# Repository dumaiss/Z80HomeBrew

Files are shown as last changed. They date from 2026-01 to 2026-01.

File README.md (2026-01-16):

# Z80 HomeBrew Single-Board Computer

A compact Z80-based single-board homebrew computer designed to run CP/M and provide classic retro I/O and expansion.

## Overview

This board implements a banked-memory Z80 system with modern conveniences (SD storage, USB peripherals) while keeping vintage-compatible subsystems (TMS9928 video, SN76489 sound). It's intended for hobbyists building or experimenting with CP/M and retro software.

## Features

- **CPU**: Z80-compatible core
- **RAM**: 512KB, banked (Z80 address banking for CP/M usage and extended RAM experiments)
- **ROM**: 32KB EEPROM for bootloader/firmware
- **Storage**: SD Card support for disk images and CP/M volumes
- **USB Serial**: USB serial port for terminal access and debug console
- **USB Input**: USB keyboard plus D-Pad support for interactive input
- **Sound**: SN76489-compatible sound chip for PSG audio
- **Video**: TMS9928-based output; YPbPr analog video output supported
- **Expansion**: mini-PCIe style expansion slot for additional cards or peripherals
- **Power**: Designed to run from a regulated 5V wall power supply

## Hardware Notes

- The 512KB RAM is banked to map into the Z80 64KB address space as needed by the firmware or CP/M.
- The 32KB EEPROM contains the primary bootloader/firmware; update via the board's programming interface (refer to device-specific docs).
- Video uses a TMS9928-compatible video pipeline exposed as YPbPr analog output; a compatible monitor or converter is required.
- Sound is provided by an SN76489-compatible PSG; connect to an amplifier or powered speakers for audio output.
- The mini-PCIe expansion slot exposes power, bus, and selected signals for optional modules; treat it as an extension header for retro or modern expansion boards.

## Getting Started

1. Prepare an SD card with a CP/M image or disk set compatible with the board.
2. Insert the SD card into the board's slot.
3. Connect YPbPr video to a compatible display, or use the USB serial console and a USB keyboard.
4. Attach a regulated 5V wall power supply (check current rating in hardware docs before powering).
5. Power on the board — the bootloader in EEPROM should initialize and boot from the SD card if present.

Notes:
- Use a terminal program (e.g., `screen`, `minicom`, or a serial terminal application) to connect to the USB serial console if you prefer working without the video output.
- If flashing firmware to the EEPROM or updating boot code, follow the project's programming instructions or tooling.

## Power

The board is designed to operate from a single regulated 5V DC wall supply. Verify the supply can deliver sufficient current for attached peripherals (SD, USB devices, any expansion cards). Avoid using unregulated or higher-voltage supplies.

## Files

See the project Licence: [Licence.md](Licence.md)

## Contributing

Contributions, improvements, and bug reports are welcome. Open issues or pull requests with hardware notes, firmware updates, or SD images that improve the CP/M experience.

---

If you want, I can add wiring diagrams, pinouts, a sample CP/M SD image guide, or a small troubleshooting section next.

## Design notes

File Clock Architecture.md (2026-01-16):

Here is the complete architectural summary for the μBITz clock system, capturing the "Parallel Clock" design using the 24.576 MHz oscillator.

---

# Homebrew Z80 Clock Distribution Architecture

## 1. Design Overview

This architecture uses a single high-speed master oscillator (**24.576 MHz**) to drive the entire system. The clock signal is split at the source ("Parallel Distribution"):

1. **Path A (Logic):** Feeds a hardware divider (74HC4040) to generate fixed, 50% duty cycle clocks for the Z80 CPU and peripherals.
    
2. **Path B (Bridge):** Feeds the ATmega328P directly, utilizing the AVR's internal prescaler to run at a safe 12.288 MHz while retaining the ability to "Turbo" to 24.576 MHz via software.

## 2. Hardware Schematic & Netlist

### Component 1: Master Oscillator

- **Part:** 24.576 MHz "Can" Oscillator (Socketed).
    
- **VCC:** 5V.
    
- **Output:** Connected to **Two** locations:
    
    1. ATmega328P Pin 9 (XTAL1).
        
    2. 74HC4040 Pin 10 (CLK).

### Component 2: Frequency Divider

- **Part:** 74HC4040 (12-Stage Binary Ripple Counter).
    
- **Input (Pin 10):** 24.576 MHz from Oscillator.
    
- **Outputs:**

|**4040 Pin**|**Output**|**Divisor**|**Frequency**|**Destination**|**Notes**|
|---|---|---|---|---|---|
|**Pin 9**|Q0|$\div 2$|12.288 MHz|_Unused_|(Available on header for testing)|
|**Pin 7**|Q1|$\div 4$|**6.144 MHz**|**Z80, SIO, CTC**|Perfect 50% Duty Cycle. Safe for NMOS.|
|**Pin 6**|Q2|$\div 8$|**3.072 MHz**|**SN76489**|Sound Chip. (Requires pitch correction).|

### Component 3: ATmega328P "Smart Bridge"

- **Input (Pin 9):** 24.576 MHz direct from Oscillator.
    
- **Pin 10 (XTAL2):** **Disconnected** (Floating).
    
- **Operation:** Acts as an SPI bridge and I/O offloader.
    
- **Speed:** Selectable 12.288 MHz (Standard) or 24.576 MHz (Turbo).

---

## 3. Software Configuration

### A. ATmega Fuses

You must set the fuses to treat the clock as an External Clock source and enable the safety divider at boot.

- **Low Fuse Byte:** `0x60` (Check specific calculator for your BOD settings).
    
    - **CKSEL[3:0]:** `0000` (External Clock).
        
    - **CKDIV8:** `0` (Programmed/Enabled). _Critical: This forces the chip to boot at ~3 MHz._

### B. ATmega Initialization Code

In your `setup()` function, you must reconfigure the prescaler to speed up the chip to 12.288 MHz.

C++

```
#include <avr/power.h>

// Define system clock for delay calculations (Safe Mode)
#define F_CPU 12288000UL 

void setup() {
    // 1. Chip boots at 3.072 MHz (24.576 / 8) due to CKDIV8 fuse.
    
    // 2. Disable Interrupts during clock change
    noInterrupts();
    
    // 3. Enable Prescaler Change
    CLKPR = (1 << CLKPCE);
    
    // 4. Set Prescaler to Divide-by-2 (0001)
    //    Target: 24.576 MHz / 2 = 12.288 MHz
    CLKPR = (1 << CLKPS0); 
    
    interrupts();
    
    // ... Rest of initialization
}
```

### C. Z80 Sound Driver (Pitch Correction)

Since the SN76489 is running at 3.072 MHz instead of the NTSC standard 3.579 MHz, audio pitches will be flat. The Z80 software must compensate.

- **Correction Factor:** $3.579545 / 3.072 \approx \mathbf{1.1652}$
    
- **Formula:** `Register_Value = Target_Frequency_Register * 1.165`

---

## 4. System Frequency Map

|**Subsystem**|**Frequency**|**Derivation**|**Notes**|
|---|---|---|---|
|**ATmega Core**|**12.288 MHz**|$24.576 / 2$|Configured via `CLKPR`. Safe & Stable.|
|**Z80 CPU**|**6.144 MHz**|$24.576 / 4$|$\sim$2% overclock from 6 MHz.|
|**Z80 UART**|**6.144 MHz**|$24.576 / 4$|Allows 57,600 baud (Divisor 10).|
|**Sound**|**3.072 MHz**|$24.576 / 8$|Flat pitch, 50% duty cycle.|
|**SD Card SPI**|**6.144 MHz**|$F_{CPU} / 2$|Max SPI speed in Safe Mode.|

## 5. Benefits of this Architecture

1. **Decoupled Stability:** The Z80 clock is generated by hardware logic. If the ATmega crashes or resets, the Z80 clock continues uninterrupted.
    
2. **Safety:** The ATmega runs within its datasheet limits (12 MHz @ 5V).
    
3. **NMOS Compatibility:** The 74HC4040 provides a clean 50% duty cycle square wave, essential for the vintage Sharp LH0080B CPU.
    
4. **Overclock Ready:** If you need more processing power for USB HID, you can change one line of code (`CLKPR=0`) to run the ATmega at 24.576 MHz without touching a soldering iron.

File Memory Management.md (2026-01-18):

# Z80 HomeBrew Single-Board Computer

**Memory & I/O Architecture Reference Manual**

## 1. Architecture Overview

This system is a Z80-based single-board computer designed for flexibility, supporting both classic "ColecoVision-style" fixed memory maps and a modern "All-RAM" banked architecture suitable for CP/M or complex homebrew software.

### Core Specifications

- **CPU:** Z80 @ 3.68MHz (or up to 8MHz depending on parts).    
- **RAM:** 512KB Static RAM (Banked).    
- **ROM:** 512KB Flash/EEPROM (Banked).    
- **Memory Controller:** Hybrid design using a **74HC273 Latch** for state storage and a **GAL22V10** for address decoding and logic injection.

---

## 2. Memory Management

The memory management system is designed with a **safe power-on default**. At power-on, the banking latch initializes to $00, placing the system in **Standard Boot Mode** - a ColecoVision-compatible configuration requiring no initialization. The system boots directly into ROM BIOS and is immediately functional. Advanced features (bank switching, All-RAM mode, CP/M) are accessed by writing to the Banking Latch at I/O Port $00.

## 2.1 Usage Patterns

### Pattern A: Simple/ColecoVision Mode (Default - No Setup Required)

**Power-on state provides:**
- ROM BIOS at $0000-$5FFF
- Work RAM at $6000-$7FFF  
- Cartridge or upper RAM at $8000-$FFFF

**No MMU configuration needed** - system is immediately ready. This mode is 
compatible with ColecoVision software and simple applications that don't 
require bank switching.

---

### Pattern B: CP/M / Advanced Mode (Requires Initialization)

For CP/M or applications requiring full 512KB RAM access:

1. **Power-on**: System starts in Boot Mode (ROM_DIS=0)
2. **ROM BIOS executes** from $0000
3. **Enable Shadow Mode**: `OUT ($00), $08` 
4. **Copy BIOS to RAM**: Use `LDIR` to copy $0000-$5FFF to RAM
5. **Switch to All-RAM**: `OUT ($00), $10`
6. **Result**: 
   - Full 512KB RAM accessible via bank switching
   - Common area at $0000-$1FFF always mapped to Bank 0 (for interrupt safety)
   - $2000-$FFFF can access any of 8 banks

See Section 4 for detailed code examples.

### Configuration Port ($00)

The memory is managed by writing to the **Banking Latch** at I/O Port **`$00`**.

| **Bit** | **Name** | **Function** |
| --- | --- | --- |
| **D0-D2** | **RAM Bank** | Selects the active 64KB RAM Bank (`0-7`) for the swappable area. |
| **D3** | **Shadow** | **0** = Normal Operation.<br><br>  <br><br>**1** = **Shadow Mode**. Writes to ROM addresses are redirected to RAM. Reads still come from ROM. Used to copy BIOS to RAM. |
| **D4** | **ROM Disable** | **0** = ROM Enabled (Boot/Standard Mode).<br><br>  <br><br>**1** = ROM Disabled (All-RAM Mode). |
| **D5-D7** | **ROM Page** | Selects the active 64KB ROM Page (`0-7`) mapped into the BIOS area. |

### Operational Modes

#### A. Standard Boot Mode (Default)

- **Condition:** `ROM_DIS = 0`.    
- **Layout:**
    
    - **$0000 - $5FFF:** ROM (BIOS).        
    - **$6000 - $7FFF:** RAM (Fixed window).        
    - **$8000 - $FFFF:** Cartridge ROM (if present) OR Upper RAM.
        
- **Behavior:** The system behaves like a standard console. Vectors at `$0000` are served from ROM.

#### B. All-RAM Mode (CP/M Mode)

- **Condition:** `ROM_DIS = 1` AND `No Cartridge`.    
- **Layout:**
    
    - **$0000 - $1FFF:** **Common RAM (Forced Bank 0)**.        
    - **$2000 - $FFFF:** Swappable RAM (Selected by `D0-D2`).
        
- **Safety Feature:** The "Common Area" logic in the GAL ensures that the bottom 8KB (`$0000-$1FFF`) **always points to Physical Bank 0**, regardless of the Bank Select bits. This prevents system crashes during interrupts (Vectors at `$0066`/`$0038` stay accessible).

---

## 3. Memory Maps

### Boot Mode (Standard)

|**Address**|**Size**|**Description**|**Physical Source**|
|---|---|---|---|
|**$0000 - $5FFF**|24KB|BIOS ROM|ROM Page `D5-D7`|
|**$6000 - $7FFF**|8KB|Work RAM|RAM Bank `D0-D2`|
|**$8000 - $FFFF**|32KB|Cartridge / RAM|Cartridge OR RAM Bank `D0-D2`|

**Note:** In Standard Boot Mode, the full 24KB ROM is accessible. When transitioning to All-RAM mode, the Common Area safety feature restricts the bottom 8KB to Bank 0.

### All-RAM Mode (ROM Disabled)

|**Address**|**Size**|**Description**|**Physical Source**|
|---|---|---|---|
|**$0000 - $1FFF**|8KB|**Common RAM**|**RAM Bank 0** (Hardware Forced)|
|**$2000 - $FFFF**|56KB|Swappable RAM|RAM Bank `D0-D2`|

> **Note:** In All-RAM Mode, if you select Bank 1 (`D0-D2 = 1`), you access Bank 1's memory from `$2000` upwards. The bottom 8KB of Bank 1 is effectively "hidden" behind the Common Area.

### External Programming (PROG Signal)
The PROG signal enables in-system programming of the Flash ROM via an external 
programmer. When PROG is asserted:
- The external programmer takes control via CPU bus mastering signals (BUSREQ/BUSACK)
- ROM_CS is enabled, SRAM_CS and CART_CS are disabled
- This allows direct Flash programming without removing the chip

**Note:** PROG is intended for development/manufacturing use only.

### Cartridge Detection
The CART_DETECT signal (active HIGH) indicates when a physical cartridge is 
inserted. This signal:
- Is pulled HIGH when a cartridge with the detection pin is inserted
- Modifies memory mapping in Standard Boot Mode to enable cartridge ROM at $8000-$FFFF
- Should be tied LOW (via pull-down) if no cartridge slot is implemented

---

## 4. Programming Model

### Example: Copying BIOS to RAM (Shadowing)

To boot CP/M, you must copy the ROM code into RAM and then switch the ROM off.

Code snippet

```
    ; 1. Enable Shadow Mode (Bit 3 = 1)
    ;    Keep ROM enabled (Bit 4 = 0)
    LD  A, %00001000   ; D3=1
    OUT ($00), A

    ; 2. Copy ROM to RAM
    ;    Reads come from ROM, Writes go to RAM (because of Shadow bit)
    LD  HL, $0000      ; Source
    LD  DE, $0000      ; Destination
    LD  BC, $6000      ; Copy 24KB
    LDIR

    ; 3. Disable ROM and Shadow Mode (Switch to All-RAM)
    ;    Bit 4 = 1 (Disable ROM), Bit 3 = 0 (Shadow Off)
    LD  A, %00010000   ; D4=1
    OUT ($00), A

    ; System is now running purely from RAM Bank 0.
```

### Example: Switching Banks in All-RAM Mode

When running in All-RAM mode, code in the **Common Area** (`$0000-$1FFF`) can safely switch banks without crashing.

Code snippet

```
    ORG $1000          ; Code located in Common Area

SWITCH_TO_BANK1:
    LD  A, %00010001   ; D4=1 (Keep ROM Off), D0=1 (Select Bank 1)
    OUT ($00), A
    
    ; Now, memory from $2000-$FFFF belongs to Bank 1.
    ; Memory from $0000-$1FFF is STILL Bank 0.
    RET
```

---

## 5. I/O Map

|**Port Range**|**R/W**|**Function**|
|---|---|---|
|**$00 - $1F**|W|**Memory Banking Latch** (See Section 2)|
|**$20 - $3F**|R/W|**SD Card / User Port** (SIO1)|
|**$40 - $5F**|R/W|**CTC** (Counter/Timer)|
|**$60 - $7F**|R/W|**Cartridge I/O Expansion**|
|**$80 - $9F**|-|_Reserved / Unused_|
|**$A0 - $BF**|R/W|**Video VDP** (TMS9928)|
|**$C0 - $DF**|R/W|**USB / Console / GPIO** (SIO0)|
|**$E0 - $FF**|R|**USB / Console / GPIO** (Mirror for Controller Reads)|
|**$E0 - $FF**|W|**Sound Generators** (SN76489 x2)|

---

## 6. Hardware Logic Definitions (WinCUPL)

These are the final logic definitions matching the architecture described above.

### A. Memory Decoder (`Z80_MEM_DECODE`)

_Implements the Banking, Shadowing, and "Common Area" safety logic._

Code snippet

```
Name     Z80_MEM_DECODE;
Partno   008;
Date     2026-01-17;
Revision 08;
Designer HomeBrew;
Company  Z80 Project;
Assembly Memory Board;
Location U_MEM_GAL;
Device   g22v10;

/* Inputs */
Pin 1  = A15;
Pin 2  = A14;
Pin 3  = A13;
Pin 4  = MREQ;        /* Active Low */
Pin 5  = RAM_SHADOW;  /* 1 = Shadow Mode */
Pin 6  = ROM_DIS;     /* 1 = Disable ROM */
Pin 7  = CART_DETECT; /* 1 = Cartridge Present */
Pin 8  = PROG;        /* 1 = Programming Mode */
Pin 9  = RD;          /* Active Low */
Pin 10 = WR;          /* Active Low */

/* Banking Latch Inputs (Reassigned to free pins) */
Pin 11 = BANK_Q0;
Pin 13 = BANK_Q1;
Pin 14 = BANK_Q2;

/* Outputs */
Pin 23 = !SRAM_CS;
Pin 22 = !ROM_CS;
Pin 21 = !CART_CS;

/* RAM Banking Address Lines (To RAM A16-A18) */
Pin 15 = RAM_A16;
Pin 16 = RAM_A17;
Pin 17 = RAM_A18;

/* Address Definitions */
BIOS_RANGE = !A15 & (!A14 # !A13);    /* $0000 - $5FFF */
COMMON_RAM = !A15 & !A14 & !A13;      /* $0000 - $1FFF (Bottom 8K) */
UPPER_32K  = A15;                     /* $8000 - $FFFF */
RAM_ONLY   = !A15 & A14 & A13;        /* $6000 - $7FFF */

/* Logic Conditions */
ALL_RAM_MODE = ROM_DIS & !CART_DETECT;
FORCE_BANK0  = COMMON_RAM & ALL_RAM_MODE;

/* Equations */
/* Force RAM Address to 0 in Common Area, otherwise pass Latch */
RAM_A16 = BANK_Q0 & !FORCE_BANK0;
RAM_A17 = BANK_Q1 & !FORCE_BANK0;
RAM_A18 = BANK_Q2 & !FORCE_BANK0;

ROM_CS = !MREQ & (PROG # (RD & !ROM_DIS & (RAM_SHADOW # BIOS_RANGE)));

CART_CS = !MREQ & !PROG & UPPER_32K & CART_DETECT & !RAM_SHADOW;

SRAM_CS = !MREQ & !PROG & (
            (RAM_SHADOW & WR) 
          # (!RAM_SHADOW & (
               (BIOS_RANGE & (WR # ROM_DIS))
             # RAM_ONLY
             # (UPPER_32K & !CART_DETECT)
            ))
          );
```

### B. I/O Decoder (`Z80_IO_DECODE`)

_Implements the I/O Map and Sound/Controller split._

_Correction:_ `RESET` logic updated to active-low input but active-high internal check.

Code snippet

```
Name     Z80_IO_DECODE;
Partno   006;
Date     2026-01-18;
Revision 03;
Designer HomeBrew;
Company  Z80 Project;
Assembly IO Board;
Location U_IO_GAL;
Device   g22v10;

/* ----------------------------------------------------------- */
/* Inputs */
/* ----------------------------------------------------------- */
Pin 1  = A7;
Pin 2  = A6;
Pin 3  = A5;

/* Control Signals (Active Low on Bus) */
Pin 4  = !IORQ;
Pin 5  = !M1;
Pin 6  = !RD;
Pin 7  = !WR;

/* RESET Logic:
   The Z80 /RESET pin is Active Low.
   Pin 8 = !RESET means the variable 'RESET' is TRUE when Pin 8 is LOW.
*/
Pin 8  = !RESET; 

/* ----------------------------------------------------------- */
/* Outputs (Active Low Chip Selects) */
/* ----------------------------------------------------------- */

/* Memory Banking Latch Control */
Pin 23 = !CS_MEMBANK_WR; /* Write: Clocks the 74HC273 (Rising Edge) */
Pin 16 = !CS_MEMBANK_RD; /* Read:  Enables the 74HC244 (Active Low Level) */

/* Peripherals */
Pin 22 = !CS_SIO1;       /* SD Card / User Port */
Pin 21 = !CS_CTC;        /* Counter/Timer */
Pin 20 = !CS_CART_IO;    /* Cartridge Expansion */
Pin 19 = !CS_VDP;        /* Video Processor */
Pin 18 = !CS_SIO0;       /* USB / Console (Read/Write) + Controller Mirror (Read) */
Pin 17 = !CS_SOUND;      /* Sound Generators (Write Only) */

/* ----------------------------------------------------------- */
/* Logic Equations */
/* ----------------------------------------------------------- */

/* ValidIO: IORQ is Low (Active), M1 is High (Inactive), NOT in Reset */
ValidIO = IORQ & !M1 & !RESET;

/* Address Decoding Blocks */
Block_00 = !A7 & !A6 & !A5; /* $00-$1F */
Block_20 = !A7 & !A6 &  A5; /* $20-$3F */
Block_40 = !A7 &  A6 & !A5; /* $40-$5F */
Block_60 = !A7 &  A6 &  A5; /* $60-$7F */
Block_A0 =  A7 & !A6 &  A5; /* $A0-$BF */
Block_C0 =  A7 &  A6 & !A5; /* $C0-$DF */
Block_E0 =  A7 &  A6 &  A5; /* $E0-$FF */

/* 1. Memory Banking ($00-$1F) */
/* Write: ValidIO + Block00 + Write Strobe */
CS_MEMBANK_WR = ValidIO & Block_00 & WR;

/* Read: ValidIO + Block00 + Read Strobe */
CS_MEMBANK_RD = ValidIO & Block_00 & RD;

/* 2. Standard Peripherals */
CS_SIO1       = ValidIO & Block_20;
CS_CTC        = ValidIO & Block_40;
CS_CART_IO    = ValidIO & Block_60;
CS_VDP        = ValidIO & Block_A0;

/* 3. Shared Block ($E0-$FF) */
/* CS_SIO0 is selected for $C0-$DF (Always) OR $E0-$FF (Read Only) */
CS_SIO0       = ValidIO & (Block_C0 # (Block_E0 & RD)); 

/* CS_SOUND is selected for $E0-$FF (Write Only) */
CS_SOUND      = ValidIO & Block_E0 & WR;
```

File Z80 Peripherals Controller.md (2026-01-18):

Here is the updated **Z80 Peripherals Controller** document, revised to match the hardware implementation found in the provided KiCad schematics.

### **Z80 I/O Subsystem — SD + Dual-USB-HID via SIO + ATmega1284P**

## **1) Overall Architecture**

### **1.1 Goals**

- **Decoupled I/O:** The ATmega1284P acts as an I/O co-processor, managing the "chunky" (SD Card) and "urgent" (USB HID) tasks via SPI, isolating the Z80 from complex protocols.
    
- **Simple Z80 Integration:** The Z80 interacts with these peripherals strictly through standard Z80 SIO UART links, treating the modern subsystems as simple serial streams.

### **1.2 Major Blocks**

- **Z80 Host:** Driven by a **14.7456 MHz** system clock oscillator (`Y1`).    
- **Clock Management:** A 4040 counter (`U3`) derives the system and peripheral clocks from the main oscillator.
    
    - **7.3728 MHz** for high-speed SIO links (SD)5.        
    - **3.6864 MHz** for the CTC and CPU system clock6.        
    - **1.8432 MHz** for standard baud rate generation (115.2k).
        
- **2× Z80 SIO/0:** Providing 4 serial channels total (`IC1`, `IC2`).      
- **Z80 CTC:** Used for the User Port baud rate generation and system timing (`IC3`).    
- **ATmega1284P:** The 5V I/O co-processor (`U4`). It connects to the SIOs via bit-banged UART links on **Port C** and manages peripherals via hardware SPI on **Port D**11.    

---

## **2) Channel Assignment & Addressing**

The hardware implementation uses the following channel mapping. Note that the MCU communicates with the SIOs using **Port C** pins.

### **2.1 SIO 0 (`IC1`) — Base Address 0xE0**

Driven by a **1.8432 MHz** clock, providing fixed **115,200 baud** (x16 divisor).

| **Channel** | **Role** | **Description** | **I/O Address (Data / Ctrl)** |
| --- | --- | --- | --- |
| **A** | **USB / GPIO** | Link to MCU for Keyboard/Mouse HID data | **0xE0 / 0xE2** |
| **B** | **Console** | Main user terminal (FTDI/Serial header) | **0xE1 / 0xE3** |

### **2.2 SIO 1 (`IC2`) — Base Address 0x20**

Driven by mixed clocks for high-speed and variable rate support.

| **Channel** | **Role** | **Description** | **I/O Address (Data / Ctrl)** |
| --- | --- | --- | --- |
| **A** | **SD Card** | High-speed link to MCU for Disk I/O (460.8k baud) | **0x20 / 0x22** |
| **B** | **User Port** | External serial port (Clocked by CTC Ch 0) | **0x21 / 0x23** |

### **2.3 Z80 CTC (`IC3`) — Base Address 0x40**

Driven by **3.6864 MHz**.

| **Channel** | **Function** | **I/O Address** |
| --- | --- | --- |
| **0** | **User UART Baud** (Generates clock for SIO1 Ch B) | **0x40** |
| **1** | General Purpose / Header Output (`TO1`) | **0x41** |
| **2** | General Purpose / Header Output (`TO2`) | **0x42** |
| **3** | General Purpose | **0x43** |

---

## **3) MCU & Data Paths**

### **3.1 MCU Pin Usage (`U4` ATmega1284P)**

The MCU uses its hardware SPI port to act as the master for the SD Card and USB Host Controller (MAX3421E), while using Port C to emulate serial links to the Z80.

- **SPI Bus (Port D):**
    
    - `PD1` (Pin 15): **~USB_CS** (Chip Select for USB).        
    - `PD2` (Pin 16): **~SD_CS** (Chip Select for SD Card).        
    - `PD3` (Pin 17): **SPI_MOSI**.        
    - `PD4` (Pin 18): **SPI_MISO**.        
    - `PD5` (Pin 19): **SPI_CLK**.
    
- **Control Signals:**
    
    - `PD0` (Pin 14): **USB_INT** (Interrupt from USB Controller).        
    - `PD6` (Pin 20): **~USB_RST** (Reset USB Controller).        
    - `PD7` (Pin 21): **~POWER_OFF** (Signal to power manager).
        
- **Z80 Link (Port C):**
    
    - **Port C (`PC0`–`PC7`)** handles the TX/RX/CTS/RTS signals connecting to the SIO chips (`IC1`/`IC2`).        

### **3.2 Clocks & Baud Rates**

- **SD Card Link (SIO1 A):**
    
    - Clock Source: **7.3728 MHz** (`CLK_7M3728`).        
    - Divisor: x16.        
    - Resulting Baud Rate: **460,800 baud**.
        
- **Console & USB Link (SIO0 A/B):**    
    - Clock Source: **1.8432 MHz** (`CLK_1M8432`).        
    - Divisor: x16.        
    - Resulting Baud Rate: **115,200 baud**.

---

## **4) Hardware Notes**

- **SD Card Presence:** The `SD_PRESENT` signal is routed to the MCU34, allowing it to detect card insertion before attempting initialization via SPI.
    
- **User Port:** The User UART (SIO1 B) baud rate is fully programmable via CTC Channel 0, allowing for non-standard or legacy baud rates independent of the fixed system clocks.
    
- **Expansion:** `TO1` and `TO2` from the CTC are routed to headers/expansion, available for external timing or triggering applications.

## 5) Programming model for Z80  

### 5.1 HID (USART0 / SIO_USB): 2-byte event records (commandless)

HID is a pure **byte stream** from MCU to Z80. Z80 reads it via SIO RX ISR. 

#### Record format (2 bytes)

- **Byte0 = META**
- `b7..b4 TYPE` (0..15)
- `b3..b2 PORT` (00=port1, 01=port2)
- `b1..b0 FLAGS` (currently 00)
- **Byte1 = DATA**
- “which key / which button / which modifier bitfield”

Suggested TYPE values:

- `0x0 KEY_DOWN` DATA = keycode
- `0x1 KEY_UP` DATA = keycode
- `0x2 MODS` DATA = mods bitfield
- `0x3 DPAD_STATE` DATA = bitfield
- `0x4 DEV_PRESENT` DATA = 0/1  

MODS bitfield (DATA for TYPE=MODS):

- b0 LCTRL, b1 LSHIFT, b2 LALT, b3 LGUI, b4 RCTRL, b5 RSHIFT, b6 RALT, b7 RGUI

> Keycode policy: keep it “neutral” (HID usage IDs or your own table). CP/M can translate in software.

#### Z80 ISR sketch (ring buffer)

```asm

; Called from IM2 when SIO_USB RX interrupt fires.

; Goal: drain SIO RX FIFO quickly, store bytes into ring.

SIO_USB_ISR:

.loop:

in a,(SIO_USB_RR0)

bit 0,a ; RX char available?

jr z,.done

in a,(SIO_USB_DATA)

call RING_PUSH_A

jr .loop

.done:

ei

reti

````

Foreground parser consumes in 2-byte chunks:

```asm

; if ring has >=2 bytes:

; meta = pop(); data = pop();

; switch(meta>>4) ...

```

---

### 5.2 SD (USART1 / SIO_SD): single-sector RAM buffer protocol

#### Key idea

- MCU holds **one sector** in RAM.
- Host decides when to load, read sequentially, patch, write sequentially, and flush.
- MCU never emits unsolicited status bytes.

#### Opcodes (1 byte each)  

- `0x10 LOAD` + `LBA32` (5 bytes total)
- `0x11 READSEQ` (1 byte cmd, MCU sends 512 bytes)
- `0x12 READRND` + `IDX16` (3 bytes cmd, MCU sends 1 byte)
- `0x13 WRITESEQ` + `LEN16` + data (3+LEN bytes)
- `0x14 WRITERND` + `IDX16` + data8 (4 bytes)
- `0x15 FLUSH` (1 byte)
- `0x16 GETSTAT` (1 byte, MCU sends 1 status byte)  

Status byte (`GETSTAT` response):
- `0x00 OK`
- nonzero = error (pick a tiny set; example)
- `0x01 NOSECTOR`
- `0x02 RANGE`
- `0x10 SD_IO` (read/write failure)  

Policy:  

- On `LOAD(new_lba)`: if current buffer is dirty → **flush it** → then load new.
- `READSEQ`: sends exactly **512 bytes**; host counts; no trailer.  

#### Z80 helper routines (sketch)

Assume you already have `SIO_SD_PUTC` and `SIO_SD_GETC` for the channel.

**LOAD** 

```asm

; HL:DE = LBA32 (little-endian or your choice; just be consistent)

SD_LOAD:
ld a,0x10
call SIO_SD_PUTC
ld a,l : call SIO_SD_PUTC
ld a,h : call SIO_SD_PUTC
ld a,e : call SIO_SD_PUTC
ld a,d : call SIO_SD_PUTC
ret

```

  **GETSTAT** 

```asm

SD_GETSTAT:
ld a,0x16
call SIO_SD_PUTC
call SIO_SD_GETC ; returns A=status
ret

```

  **READSEQ → buffer[512]**  

```asm

; IX points to destination buffer

SD_READSEQ_512:
ld a,0x11
call SIO_SD_PUTC
ld b,0 ; 256
ld c,2 ; 2 blocks of 256 = 512

.next256:
push bc
ld b,0

.loop256:
call SIO_SD_GETC
ld (ix+0),a
inc ix
djnz .loop256
pop bc
dec c
jr nz,.next256
ret

```

**WRITESEQ (512) from buffer**

```asm

; IX points to source buffer
SD_WRITESEQ_512:
ld a,0x13
call SIO_SD_PUTC

; LEN16 = 0x0200
xor a
call SIO_SD_PUTC ; LEN lo = 0x00
ld a,0x02
call SIO_SD_PUTC ; LEN hi = 0x02
ld b,0
ld c,2

.next256w:
push bc
ld b,0

.loop256w:
ld a,(ix+0)
inc ix
call SIO_SD_PUTC
djnz .loop256w
pop bc
dec c
jr nz,.next256w

ret

```

**FLUSH**

```asm

SD_FLUSH:
ld a,0x15
call SIO_SD_PUTC
ret

```

**Recommended calling pattern**

- Read sector:
- `SD_LOAD(lba)` → `SD_GETSTAT()` (optional check)
- `SD_READSEQ_512()` → (use data)

- Write whole sector:
- `SD_LOAD(lba)` (optional if you want read-modify-write)
- `SD_WRITESEQ_512()`
- `SD_FLUSH()` → `SD_GETSTAT()` (check)

---

## 6) MCU firmware notes (non-normative, just to align expectations)

- FreeRTOS is optional; with ATmega1284P it’s feasible.
- Priority rule:
- HID task is “fast + frequent” (driven by MAX3421E INT)
- SD task is “slow + chunky” (SPI block transfers)
- Since HID and SD have **separate UARTs**, you don’t get priority inversion on the Z80 side.

---

## 7) What’s deliberately _not_ specified

- Exact keycode mapping (ASCII vs HID usages vs your own table): **software choice**
- Any checksum/CRC/framing on UART: **nope**
- Fancy caches: **nope** (only one working sector)
- “Perfect reliability under abuse”: **nope** (bench machine, not a product)

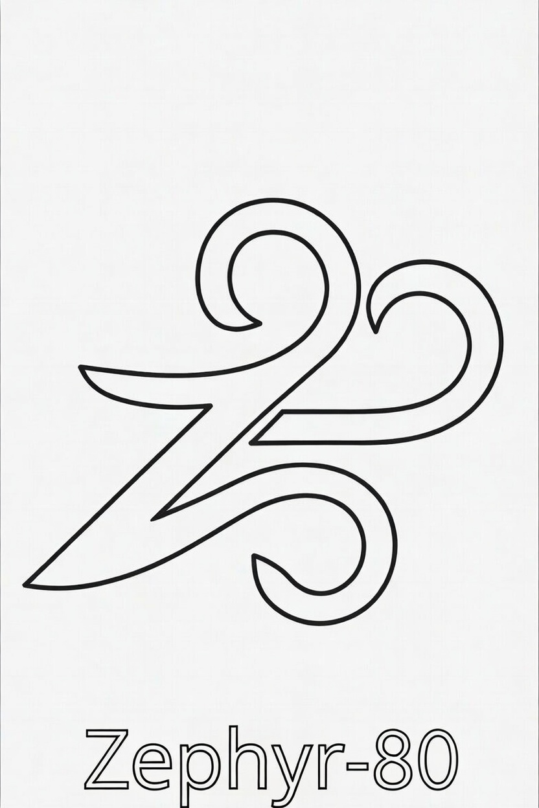
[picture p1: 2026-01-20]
Zephyr-80-Logo.jpg

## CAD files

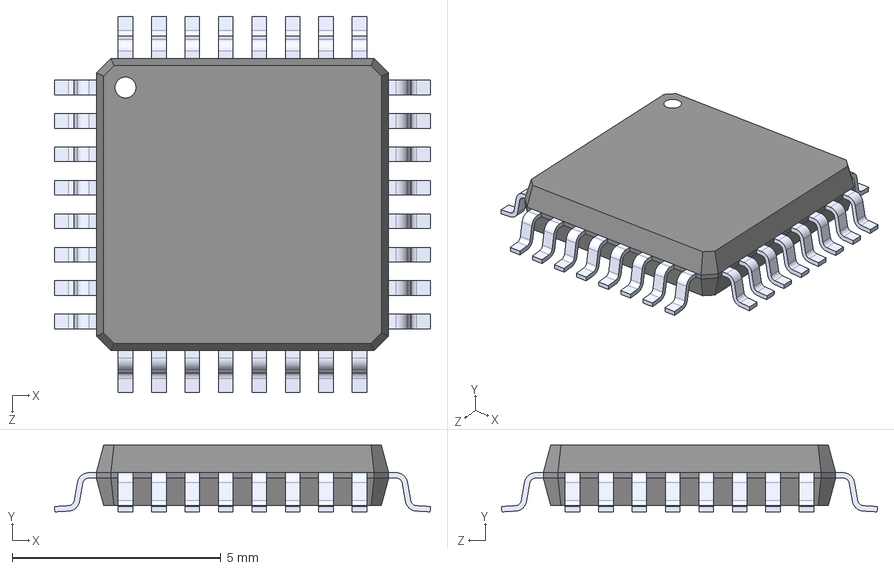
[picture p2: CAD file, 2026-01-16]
Schem/Z80HomeBrew/Footprints/TUSB2046BVFR.step
9.00 x 1.60 x 9.00 mm

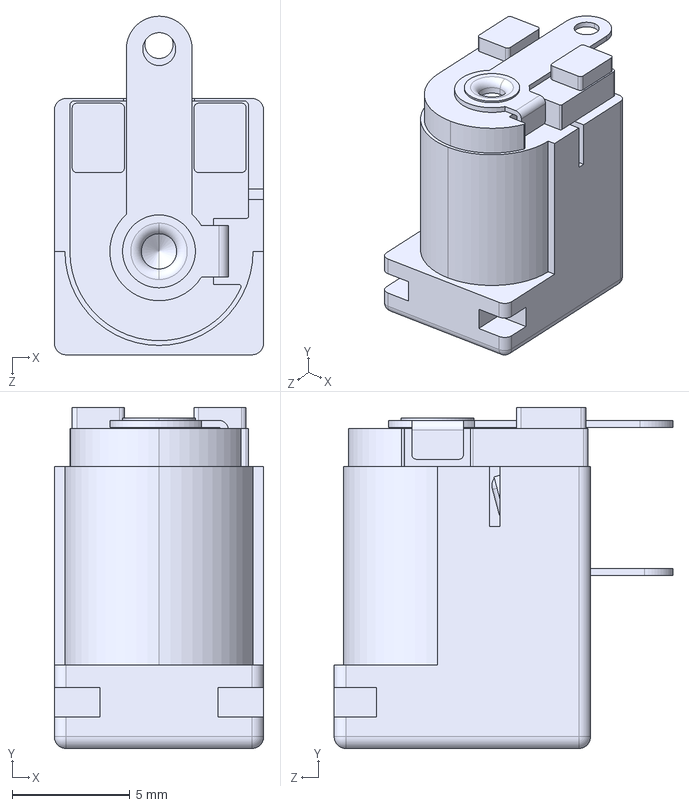
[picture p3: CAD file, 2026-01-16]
Schem/Z80HomeBrew/Footprints/PJ-037A.step
8.90 x 14.5 x 14.4 mm

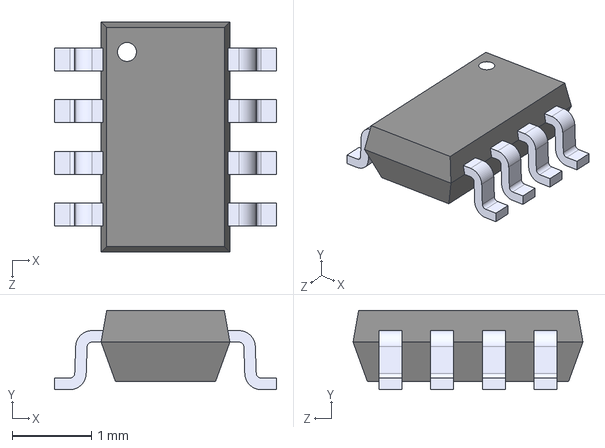
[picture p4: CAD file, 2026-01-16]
Schem/Z80HomeBrew/Footprints/LTC2954CTS8-2_TRMPBF.step
2.80 x 1.00 x 2.90 mm

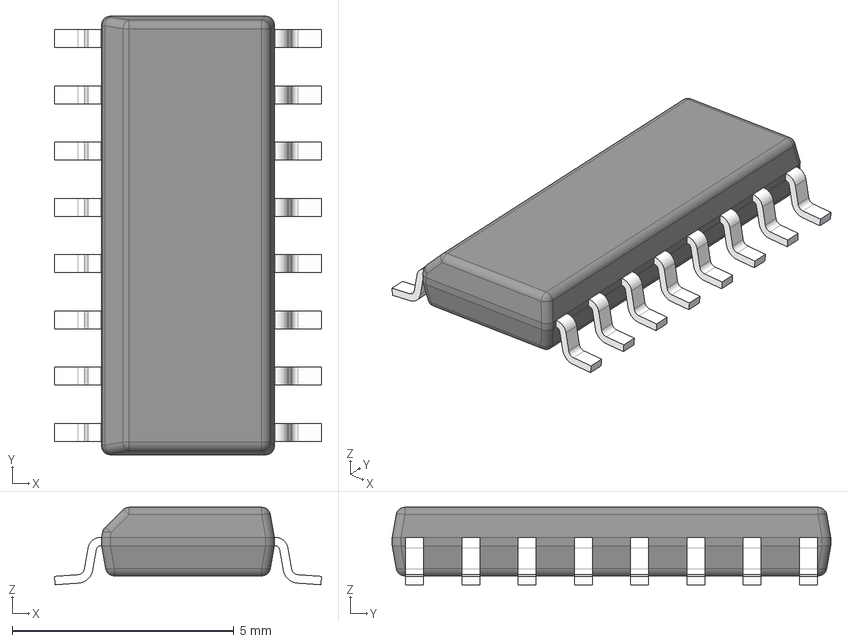
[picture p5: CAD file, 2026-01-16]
Schem/Z80HomeBrew/Footprints/D0016A.stp
6.03 x 9.90 x 1.75 mm
BODY-SO
LEAD-SO x 16
PIN1-ID

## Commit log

2026-01-16 First draft, IO
    [D0016A.stp, LTC2954CTS8-2_TRMPBF.step, PJ-037A.step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]
2026-01-18 Added sound, fixed safe space in memory map, updated CPU address decoding schematic.
    [CPU_AddressDecoding.kicad_sch, Sound.kicad_sch, Z80HomeBrew.kicad_sch]
2026-01-18 Added the ability to read from the banking registers via IN instructions.
    [CPU_AddressDecoding.kicad_sch]
